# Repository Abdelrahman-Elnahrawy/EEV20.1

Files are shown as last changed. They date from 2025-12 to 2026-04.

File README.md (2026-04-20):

# EEV20.1 – Emergency Electronic Ventilator

<p align="center">
  EEV20.1 3D Model
</p>

<p align="center">
  
  
  
  
</p>
</p>

---

## 📌 Overview

**EEV20.1** is an **Emergency Electronic Ventilator prototype** developed as an open-source engineering project.  
The goal of this project is to demonstrate a **complete ventilator system design**, including:

- Mechanical structure
- Pneumatic system
- Embedded firmware
- Control logic
- Documentation & 3D visualization

> ⚠️ **Disclaimer:**  
> This project is intended **for educational, research, and prototyping purposes only**.  
> It is **NOT a certified medical device** and must not be used for real patients without proper medical approvals.

---

## 🎥 3D Model Preview

The following GIF shows the **actual 3D model** included in this repository:

<p align="center">
  EEV20.1 3D Model
</p>

The original 3D assets are available in **GLB format** inside the `docs/` directory.

---
🖼️ Circuit Diagram
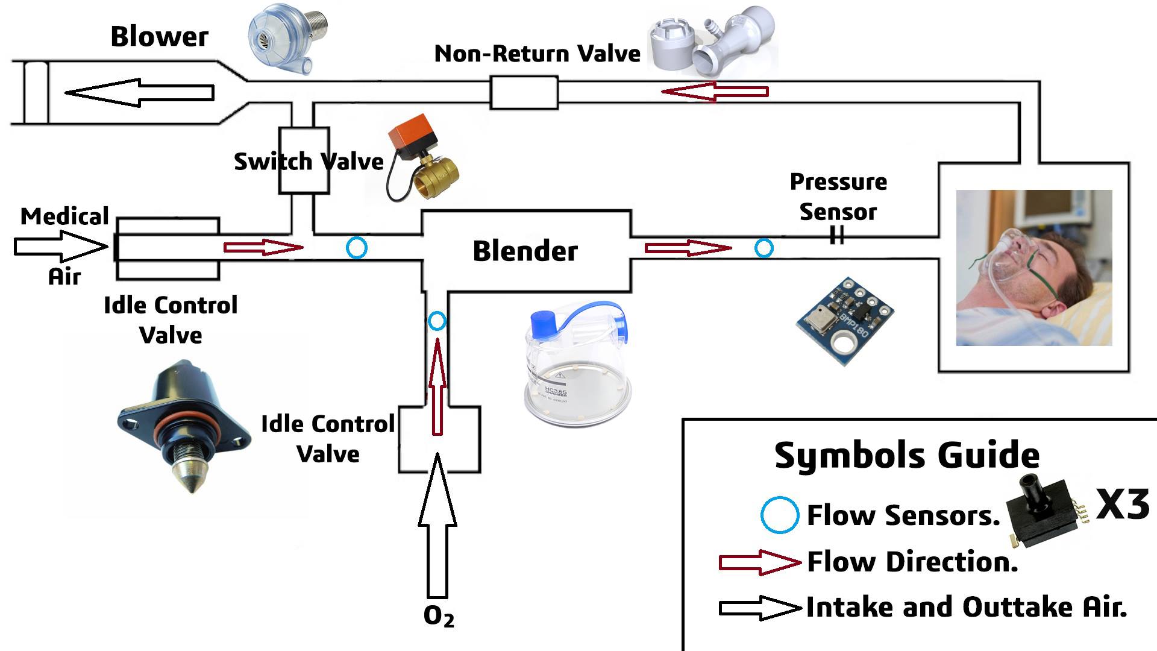
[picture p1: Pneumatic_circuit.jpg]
EEV20.1 Pneumatic Circuit
<p align="center">

*Figure 2: Pneumatic schematic showing flow paths and control valves.*

### 🔍 Operational Principle / فكرة العمل

* **Mixing Phase (مرحلة الخلط):** Controlled by stepper motors, the Air and $O_2$ valves open to a specific ratio to achieve the target $FiO_2$.
* **Delivery Phase (مرحلة الضخ):** The mixture is pressurized and delivered to the patient through a regulated flow path.
* **Exhalation (الزفير):** The system manages the exhalation valve to maintain **PEEP** (Positive End-Expiratory Pressure) if required.

---

## 📂 Repository Structure / هيكل المشروع

```text
EEV20.1/
├── .gitattributes                       # Git configuration for line endings, etc.
├── LICENSE                              # MIT License file
├── bill of materials.docx                # Complete parts list for the ventilator
├── EEV 20 ventilator User manual.pdf    # Main user manual PDF
├── Product_vision.gif                    # GIF preview of the 3D model
├── Pneumatic_circuit.jpg                 # Pneumatic system diagram
├── README.md                             # This file
├── docs/                                 # 3D models & viewer assets
│   ├── Body Design Containing Control Components.SLDPRT  # Solidworks CAD file of main enclosure & control
│   ├── index.html                        # Web page for 3D model viewing
│   ├── PCBs_Schematics.pdf               # PDF of PCB schematics
│   ├── Product_vision.glb                # 3D model of final product (GLB format)
│   ├── Product_vision.mp4                # Video render of the product
│   ├── Prototype.glb                     # 3D model of prototype version
│   └── Prototype.mp4                     # Video render of prototype
├── Render Prev images/                    # Screenshots & renders of components
│   ├── 2 Idle Valves.PNG
│   ├── Blower.PNG
│   ├── Design.PNG
│   ├── Humidifier.PNG
│   ├── keypad.PNG
│   ├── LCD.PNG
│   └── non return valve.PNG
└── Ventilation_Firmware_ATmega128A/      # Embedded firmware for ATmega128A
    ├── README.md                         # Firmware-specific README with build instructions
    ├── main.c                            # Main program entry point
    ├── app/                              # Application-level logic
    │   ├── ventilation_fsm.c             # Finite State Machine implementation
    │   └── ventilation_fsm.h             # FSM header
    ├── config/                           # Configuration files
    │   └── ventilation_config.h          # Configurable parameters for firmware
    ├── control/                          # Control modules
    │   ├── ventilation_idle_stepper_control.c  # Idle stepper motor control logic
    │   └── ventilation_idle_stepper_control.h  # Header for stepper control
    ├── drivers/                          # Low-level hardware drivers
    │   ├── lcd_driver.c                  # LCD screen driver
    │   ├── lcd_driver.h                  # LCD driver header
    │   ├── stepper_driver.c              # Stepper motor driver
    │   └── stepper_driver.h              # Stepper driver header
    ├── logic/                             # Computational logic modules
    │   ├── ventilation_machine_calculations.c   # Core ventilation calculations
    │   └── ventilation_machine_calculations.h   # Header for calculations
    ├── safety/                            # Safety and alarms
    │   ├── ventilation_safety.c          # Safety functions (limits, alarms)
    │   └── ventilation_safety.h          # Header for safety functions
    ├── ui/                                # User interface modules
    │   ├── ventilation_lcd.c             # LCD interface code
    │   └── ventilation_lcd.h             # LCD interface header
    └── v3_old/                            # Previous versions / prototypes
        ├── Air_flow_sensors_V1/          # Air flow sensor firmware
        │   ├── Air_Flow_Sensors_V1.cpp
        │   ├── Air_Flow_Sensors_V1.h
        │   └── Air_flow_sensors_V1.ino
        ├── mqtt_ventilation_machine_V1/  # MQTT-enabled prototype
        │   ├── ESP8266_MQTT_Client_V1.cpp
        │   ├── ESP8266_MQTT_Client_V1.h
        │   └── ESP8266_MQTT_Client_V1.ino
        ├── ventilation_control_pad_V2/   # Control pad prototype V2
        │   ├── ventilation_control_pad_V2.cpp
        │   ├── ventilation_control_pad_V2.h
        │   └── ventilation_control_pad_V2.ino
        ├── ventilation_idle_stepper_control/  # Old idle stepper control
        │   ├── ventilation_idle_stepper_control.cpp
        │   ├── ventilation_idle_stepper_control.h
        │   └── ventilation_idle_stepper_control.ino
        ├── ventilation_lcd_V3/            # Old LCD V3 code
        │   ├── ventilation_lcd_V3.cpp
        │   ├── ventilation_lcd_V3.h
        │   └── ventilation_lcd_V3.ino
        └── ventilation_machine_calculations/  # Old calculation modules
            ├── ventilation_machine_calculations.cpp
            ├── ventilation_machine_calculations.h
            └── ventilation_machine_calculations.ino
                          # Main project readme
```

## 🛠 System Components

### 🔌 Embedded System
- **Microcontroller:** ATmega128A
- **Language:** C (Bare-metal / AVR)
- **Architecture:** Modular & layered
- **Purpose:** Motor control, timing, safety logic, system states

### 🫁 Pneumatic System
- Pressure control
- Air flow regulation
- Safety relief mechanisms  
(see `Pneumatic_circuit.jpg`)

### 🧱 Mechanical Design
- Custom enclosure
- Motor-driven compression mechanism
- Designed for manufacturability & prototyping

---

## 📘 Documentation

Available documents include:

- **User Manual**
- **Pneumatic Circuit Diagram**
- **PCB & Electrical Schematics**
- **Project Reports & Presentations**

All documents are available directly in the repository as PDFs or inside the `Documentation/` folder.

---

yaml
Copy code

It includes:
- Low-level drivers
- Control logic
- Timing & safety handling
- Modular structure suitable for extension

📄 Please refer to the **README inside the firmware folder** for:
- Build instructions
- Code architecture
- Configuration details

---

## ⚠️ Safety Notice

- ❌ Not FDA / CE approved  
- ❌ Not clinically tested  
- ❌ Not intended for real medical use  

This project is shared **for learning and engineering demonstration only**.

---

## 📜 License

This project is licensed under the **MIT License**.

MIT License

Copyright (c) 2025 Abdelrahman Elnahrawy

Permission is hereby granted, free of charge, to any person obtaining a copy
of this software and associated documentation files...

yaml
Copy code

---

## 👤 Author

**Abdelrahman Elnahrawy**  
Embedded Systems & Mechatronics Engineer  

🔗 GitHub:  
https://github.com/Abdelrahman-Elnahrawy

---

## ⭐ Acknowledgment

If this project helped you learn or inspired your work, consider starring the repository ⭐  
and sharing it with the engineering community.

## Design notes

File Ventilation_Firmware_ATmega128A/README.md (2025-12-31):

# 🫁 Ventilation Machine Firmware (ATmega128A)








A modular, non-blocking firmware architecture for a microcontroller-based mechanical ventilation system, designed for **ATmega128A**.

This project focuses on **clean separation of concerns**, **safety**, and **real-time behavior**, making it suitable for research, academic, and prototype medical devices.

---

## 📌 Features

- ✅ Non-blocking architecture (millis / timers)
- ✅ Finite State Machine (FSM) control
- ✅ Safety & alarm layer (leakage detection)
- ✅ Stepper-based air & oxygen valve control
- ✅ LCD-based user interface (16x4)
- ✅ Expandable and RTOS-ready structure
- ✅ Medical-oriented design separation

---

## 🧠 System Architecture

The firmware is divided into clear functional layers:

UI (LCD)
│
FSM (Application Logic)
│
Control (Stepper / Valves)
│
Logic (Breathing Timing & Calculations)
│
Safety (Flow Validation & Alarms)
│
Drivers (LCD / Stepper)

yaml
Copy code

Each layer is **independent**, testable, and reusable.

---

## 📁 Folder Structure

Ventilation_Firmware_ATmega128A/
│
├── main.c
│
├── app/
│ ├── ventilation_fsm.h
│ ├── ventilation_fsm.c
│
├── control/
│ ├── ventilation_idle_stepper_control.h
│ ├── ventilation_idle_stepper_control.c
│
├── logic/
│ ├── ventilation_machine_calculations.h
│ ├── ventilation_machine_calculations.c
│
├── ui/
│ ├── ventilation_lcd.h
│ ├── ventilation_lcd.c
│
├── safety/
│ ├── ventilation_safety.h
│ ├── ventilation_safety.c
│
├── drivers/
│ ├── stepper_driver.h
│ ├── stepper_driver.c
│ ├── lcd_driver.h
│ ├── lcd_driver.c
│
├── config/
│ └── ventilation_config.h
│
└── README.md

yaml
Copy code

---

## ⚙️ Hardware Requirements

- **Microcontroller:** ATmega128A  
- **Display:** 16x4 LCD (HD44780 compatible)  
- **Actuators:** Stepper motors (Air & Oxygen idle valves)  
- **Sensors:**  
  - Air flow sensor  
  - Oxygen flow sensor  
- **Drivers:** ULN2003 / A4988 (or similar)

---

## 🔄 Finite State Machine (FSM)

The ventilation cycle is controlled using an FSM:

| State | Description |
|---|---|
| INIT | System initialization |
| STANDBY | Idle state |
| INHALE | Active air & oxygen delivery |
| EXHALE | Passive exhalation |
| ALARM | Safety fault detected |

State transitions are **time-based and safety-driven**.

---

## 🛡️ Safety Mechanism

The safety layer continuously verifies:

Patient Flow ≈ Air Flow + Oxygen Flow

yaml
Copy code

If deviation exceeds ±5%:
- Alarm state is triggered
- Valve motion stops
- LCD shows leakage warning

---

## 🧮 Breathing Calculations

- Inhale / Exhale timing derived from:
  - Respiratory rate
  - I:E ratio
- All timing is **non-blocking**
- Ready for pressure-based termination upgrade

---

## 📺 User Interface (LCD)

The LCD displays:

- Maximum Pressure
- Oxygen %
- Respiratory Rate
- Tidal Volume
- I/E Ratio
- Ventilation Mode
- Alarm Messages

---

## 🔧 Stepper Control Logic

Stepper motors regulate:
- Air valve opening
- Oxygen valve opening

Control is based on:
- Required flow (calculated)
- Measured flow (sensor feedback)

> Structure is PID-ready (future upgrade).

---

## 🚀 How to Build

- Toolchain: **AVR-GCC**
- IDEs:
  - MPLAB X
  - Atmel Studio
  - PlatformIO

Compile and flash to ATmega128A using your preferred programmer.

---

## ⚠️ Disclaimer

> **This project is for educational and research purposes only.**  
>  
> The algorithms and calculations are **NOT medically certified** and **must not** be used in life-support systems without proper validation, certification, and regulatory approval.

---

## 👨‍💻 Author

**Abdelrahman Elnahrawy**  
Embedded Systems & R&D Engineer  

---

## 📜 License

MIT License

Permission is hereby granted, free of charge, to any person obtaining a copy  
of this software and associated documentation files (the "Software"), to deal  
in the Software without restriction.

---

## 🔮 Future Improvements

- PID-based flow control
- Pressure-triggered inhale termination
- EEPROM patient profiles
- FreeRTOS port
- MQTT / Telemetry support
- SD card data logging

---

⭐ If you find this project useful, feel free to star the repository.

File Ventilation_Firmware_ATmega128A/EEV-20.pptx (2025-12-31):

## EEV-20.1

ETNAFS Team

## Medical ventilators and COVID-19

- 30% of Covid-19 hospitalized patients are likely to require mechanical ventilation (estimated 450,000 ventilator world wide in ninth of April 2020)
- The mechanical ventilators prices can range from $5,000 to $50,000.

## EEV-20.1

- EEV-20.1 have 3 ways of power
1. Internal rechargeable battery sustain the device for more than 1 hour.
2. 12Volt 3 ampere power supply.
3. Two 9 volt batteries.

## EEV-20.1

- Adjustable modes
            1. Continuous Positive Airway Pressure. (CPAP)
            2. Continuous Mandatory Ventilation. (CMV)
            3. Synchronous Intermittent Mandatory Ventilation. (SIMV)
            4. Airway Pressure Release Ventilation. (APRV)
            5. Pressure Support Ventilation. (PSV)
- Range 5 to 37 cm H O adjustable in 1 cmH O increment(+-0.001cmH O).
- Expiratory ratio (I:E) adjustable in the range 1.0 to 4.0 in 1 increment.
- Range 10 to 30 breaths per minute in increments of 1 (+-1breath).
- Tidal Volume (Vt) optionally Range 250 to 800 ml in steps of 10ml (+-30ml).
- Oxygen percent control range 21% to 100% increments of 1% (+-2 %).

2

2

2

## EEV-20.1 works in two different enviroments

1. Hospital (medical air system)


## EEV-20.1 works in two different enviroments

2. Field hospital

## Monitoring and Control EEV-20.1

Step 1
Install ETNAFS App.
Step 2
Scan Device QR-code
Step 3
Monitor the graphs

- Monitor from any device by MQTT
- Easy to control

## EEV-20.1 Mechanical Properties

1- Simplicity.
2- Low Weight ( Doesn’t Exceed 3kg )
3- Will be injected in a Plastic Mold (Material - - -> Plastic ABS)
4- Each Mechanical & Pneumatic Component are widely available in Egypt

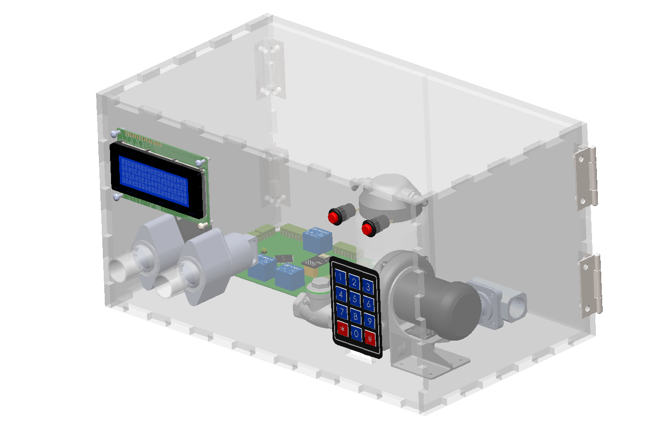
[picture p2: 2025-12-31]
Render Prev images/Design.PNG

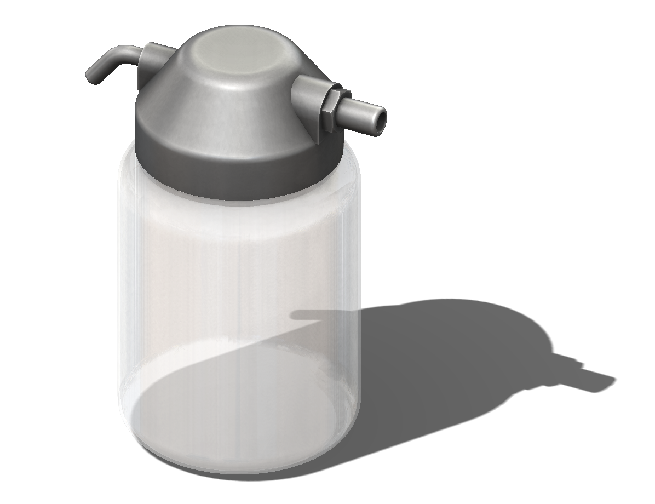
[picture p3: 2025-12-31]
Render Prev images/Humidifier.PNG

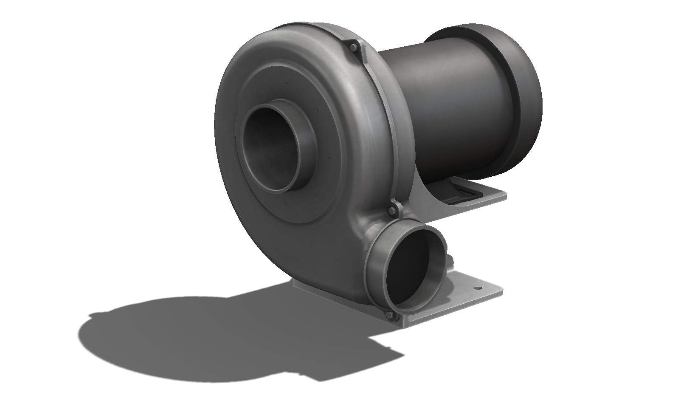
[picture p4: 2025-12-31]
Render Prev images/Blower.PNG

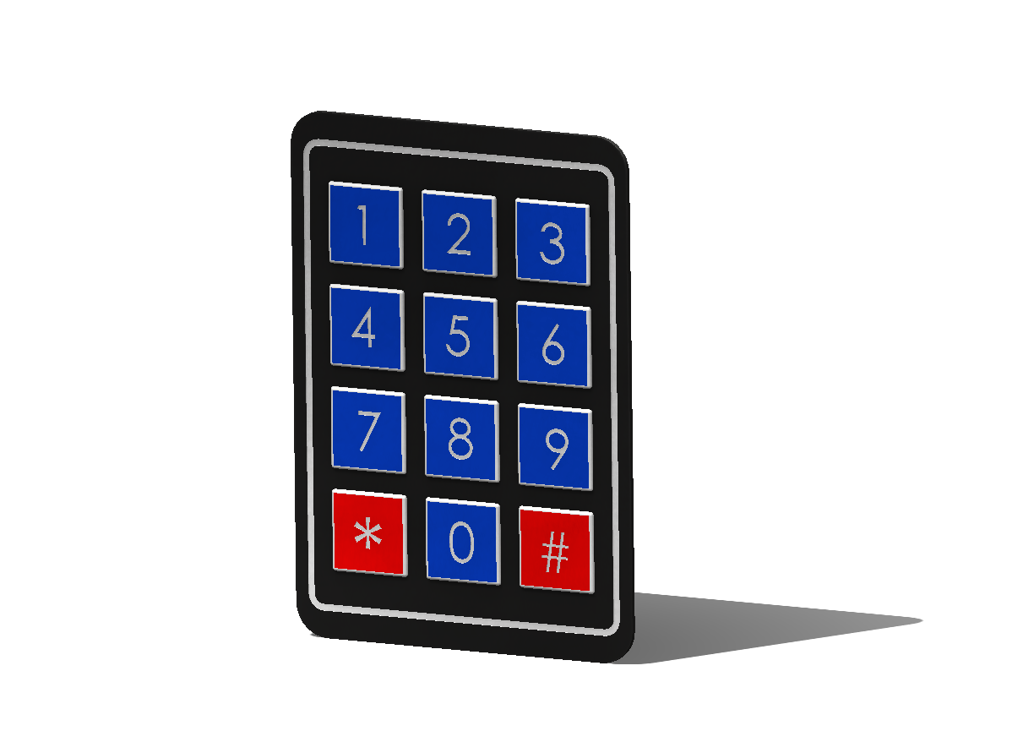
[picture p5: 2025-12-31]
Render Prev images/keypad.PNG

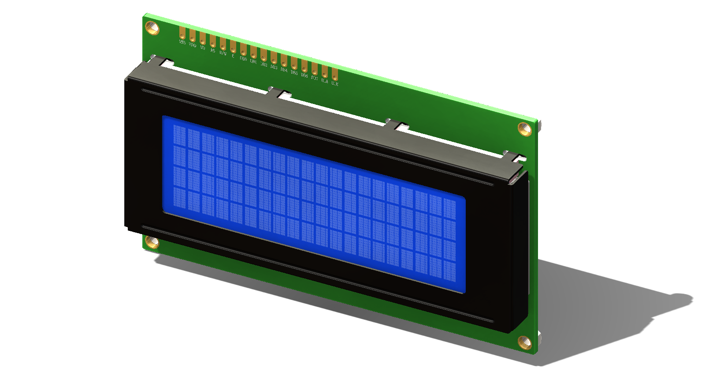
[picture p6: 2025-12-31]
Render Prev images/LCD.PNG

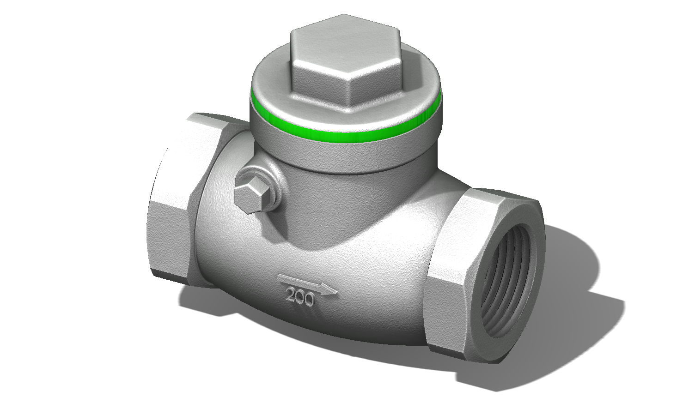
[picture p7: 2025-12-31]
Render Prev images/non return valve.PNG

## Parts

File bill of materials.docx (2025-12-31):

Part name | description | No. | Price each | Price
IAC valve 4-pins | Any 4 pins valve will work | 2 | 10 USD | 20 USD
Non-return Valve | | 1 | 1USD | 1USD
Solenoid Switch Valve | | 1 | 4USD | 4USD
DC motor | 12V DC 6000 RPM | 1 | 15 USD | 15USD
Atmega 128A/AU | Datasheet (http://ww1.microchip.com/downloads/en/devicedoc/atmel-8151-8-bit-avr-atmega128a_datasheet.pdf) | 1 | 4 USD | 4USD
ESP-01 | Wi-Fi module | 1 | 4USD | 4USD
L298N | Datasheet (https://www.sparkfun.com/datasheets/Robotics/L298_H_Bridge.pdf) | 2 | 2USD | 4USD
BMP 180 (Bosch) | Datasheet (https://cdn-shop.adafruit.com/datasheets/BST-BMP180-DS000-09.pdf) | 1 | 4 USD | 4USD
MXPM5053 GS | Datasheet (https://www.nxp.com/docs/en/data-sheet/MPX2053.pdf) | 3 | 2 USD | 6USD
AD623 | Analog convertor for MXPM5053 GS | 3 | 2USD | 6USD
LCD 1604A | | 1 | 5USD | 5USD
Relay 5V+BC547 transistor+ 2N2007diode | More than 2A/12V | 1 | 0.5 USD | 0.5USD
Resistors/Tubes/Wires | | | | 2USD
Phoenix Contact MSTBA Series | 2*8 - Pin 12*2-Pin | | | 5USD
PCB | | | | 5USD
Ultracell Battery (UL5-12) | Ultracell Battery (UL5-12) Sealed Lead Acid Battery (12V/5A) | 1 | 15USD | 15USD
Estimated body cost in industrial production (1000-5000)( ABS plastic) | | | | 15USD
Total cost | | | | 115.5USD

ALL THE COMPONENTS PRICES DECREASE SIGNIFICANTLY IN INDUSTRIAL PRODUCTION

ESTIMETIED COST OF EACH DEVICE IN INDUSTRIAL PRODUCTION 70USD

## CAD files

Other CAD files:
docs/Body Design Containing Control Components.SLDPRT

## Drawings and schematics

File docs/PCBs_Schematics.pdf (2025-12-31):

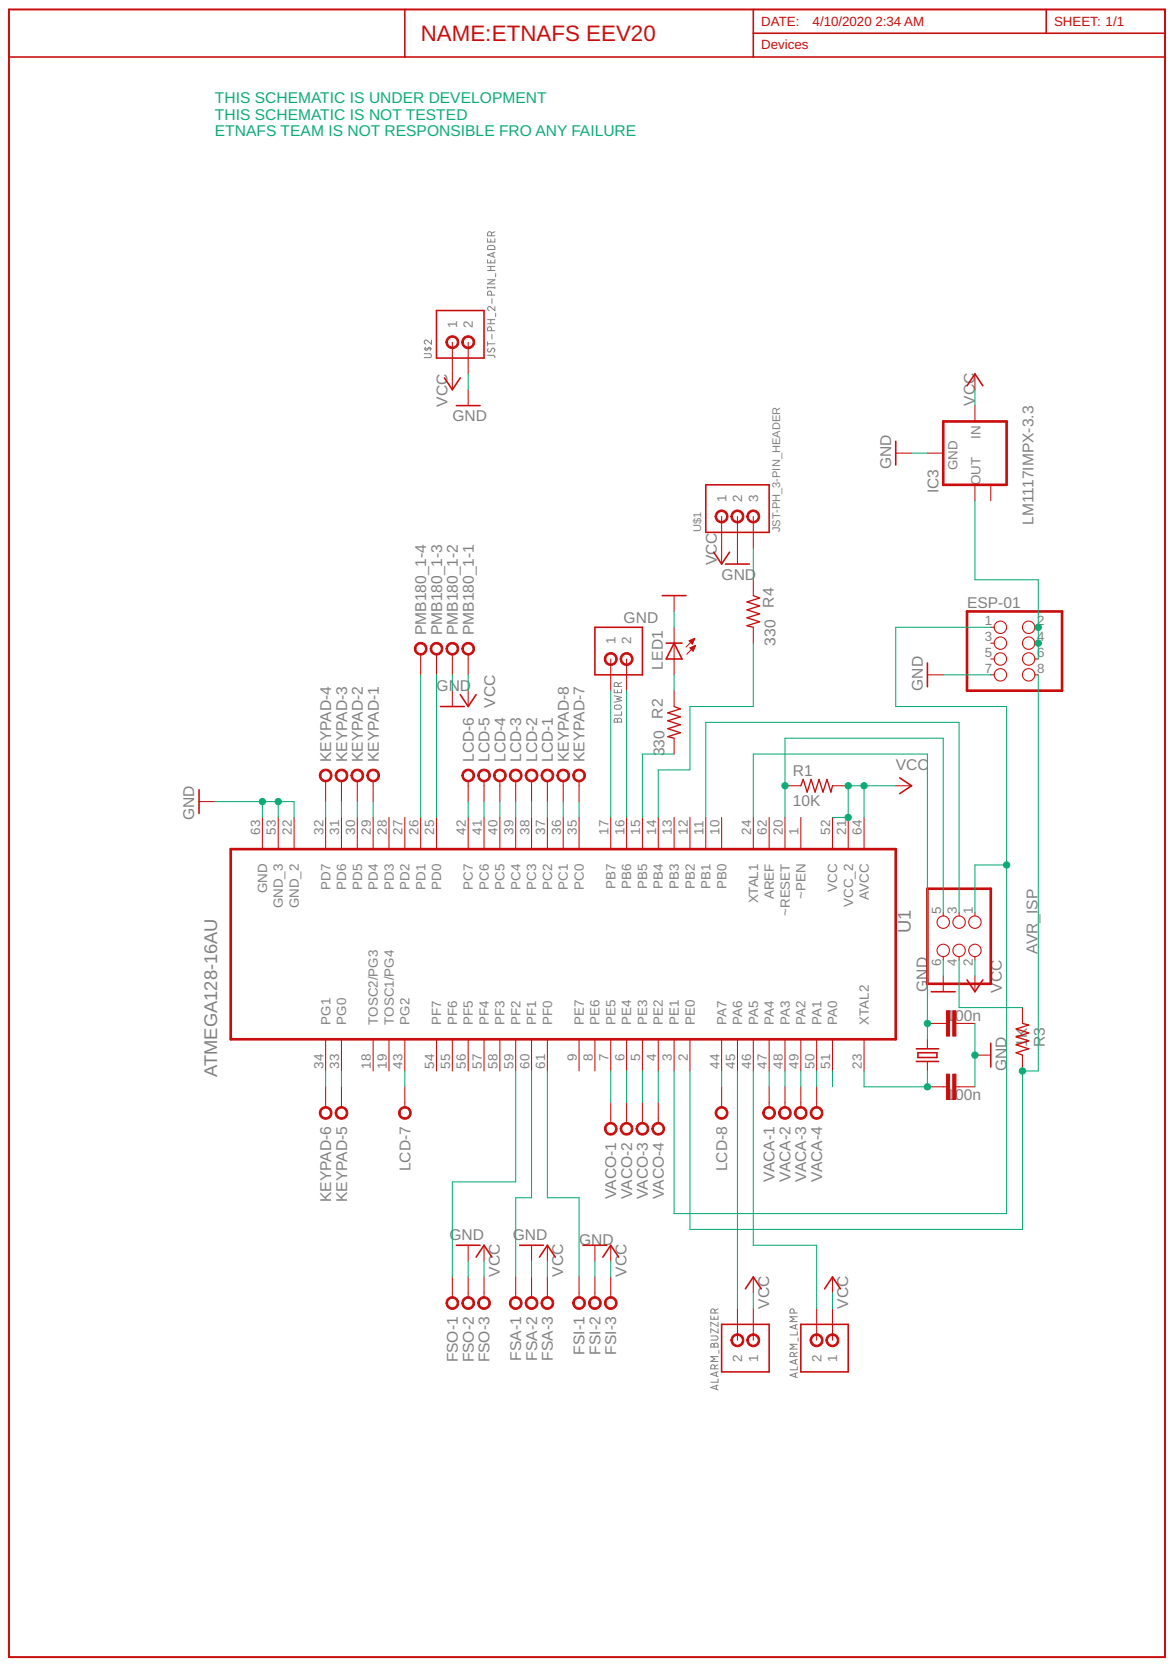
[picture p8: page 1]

2 NAME: DATE: Devices SHEET: ETNAFS EEV20

THIS SCHEMATIC IS NOT TESTED
ETNAFS TEAM IS NOT RESPONSIBLE FRO ANY FAILURE

KEYPAD-1 KEYPAD-2 KEYPAD-3 KEYPAD-4 KEYPAD-5 KEYPAD-6

VACO-1 VACO-2 VACO-3 VACO-4 VACA-1 VACA-2 VACA-3 VACA-4

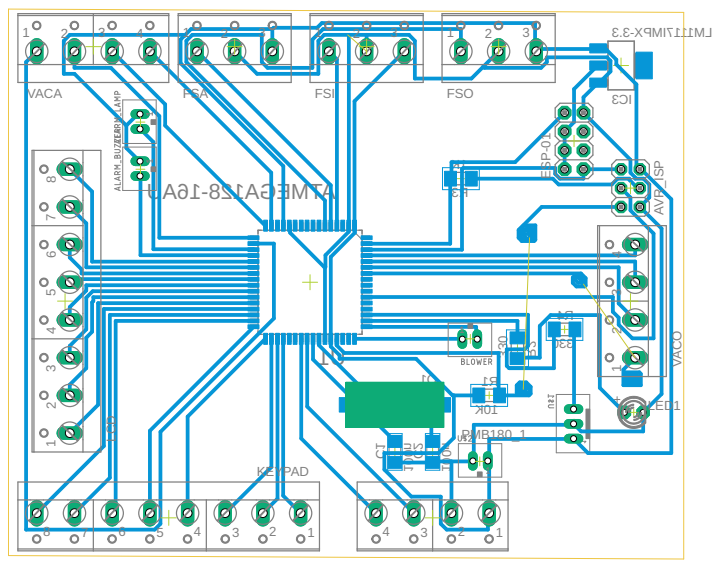
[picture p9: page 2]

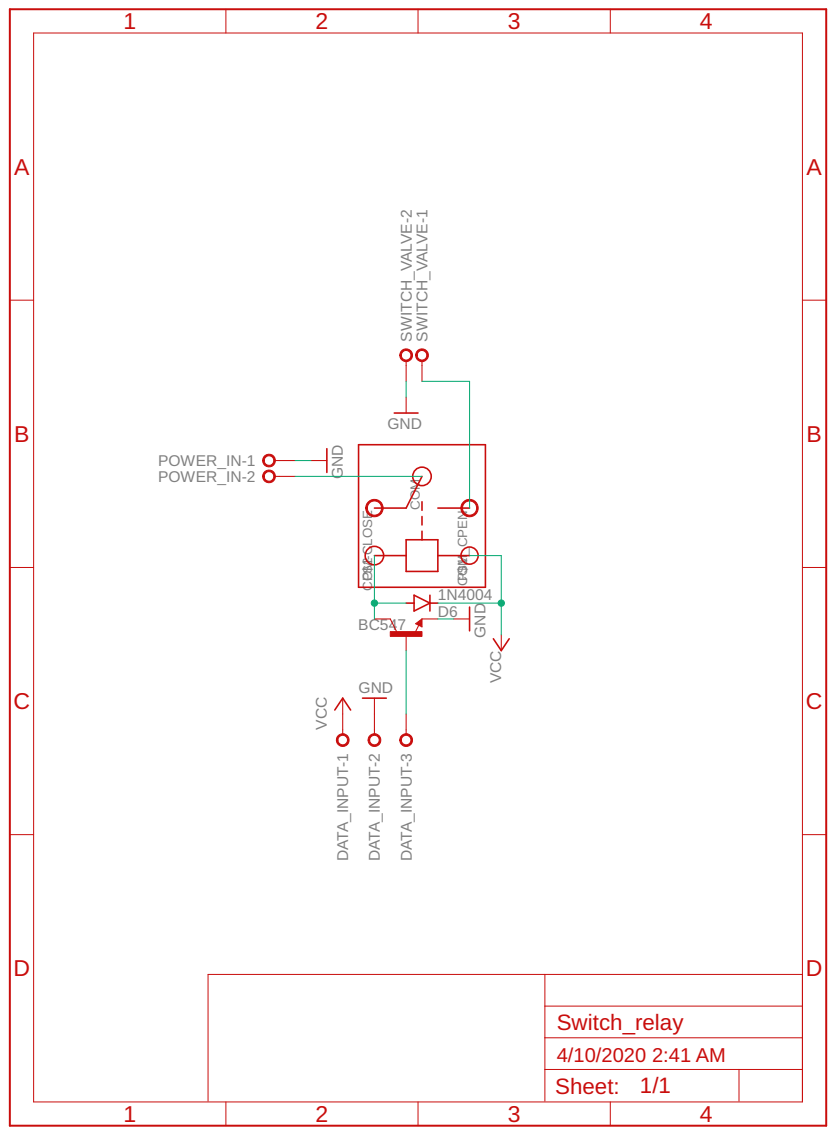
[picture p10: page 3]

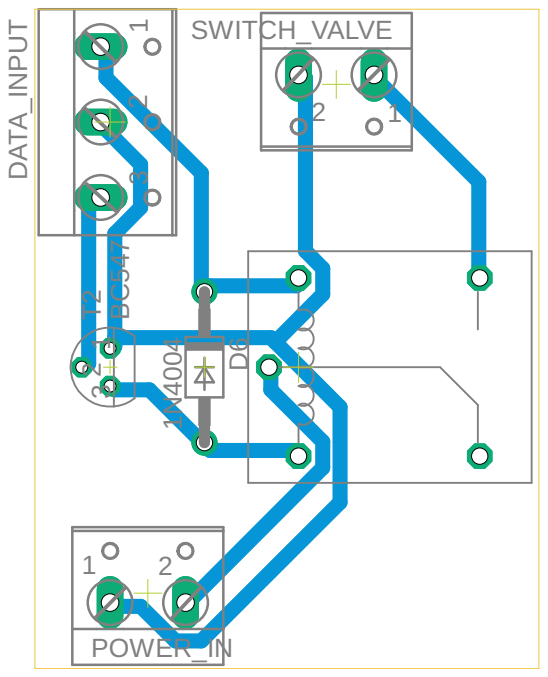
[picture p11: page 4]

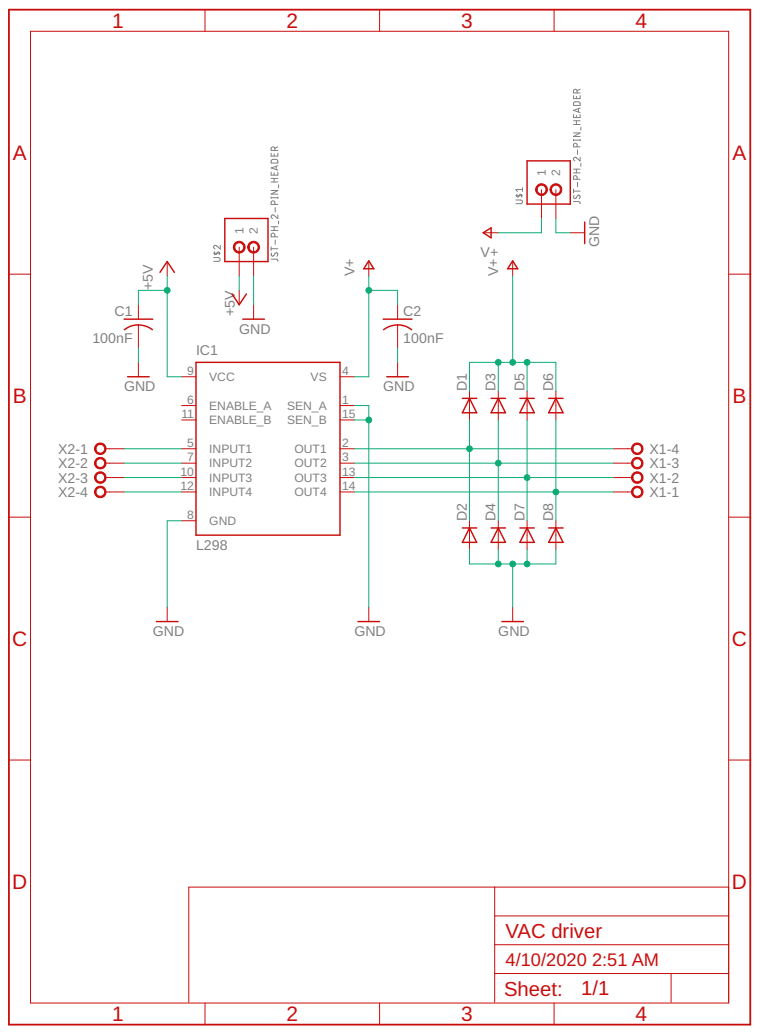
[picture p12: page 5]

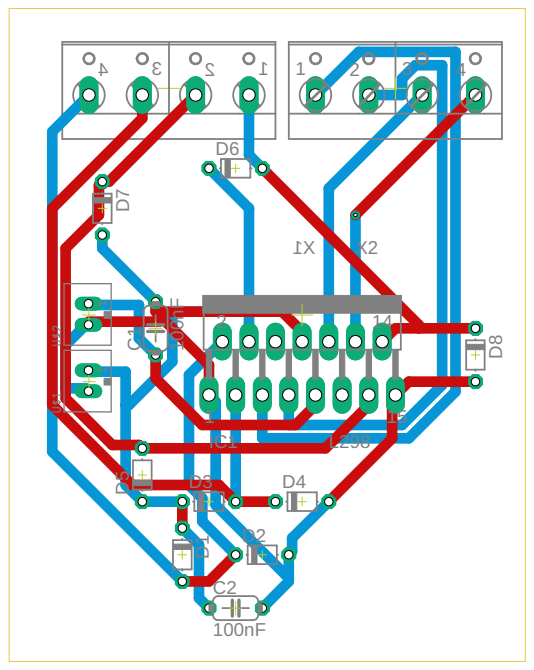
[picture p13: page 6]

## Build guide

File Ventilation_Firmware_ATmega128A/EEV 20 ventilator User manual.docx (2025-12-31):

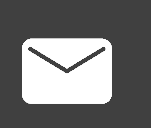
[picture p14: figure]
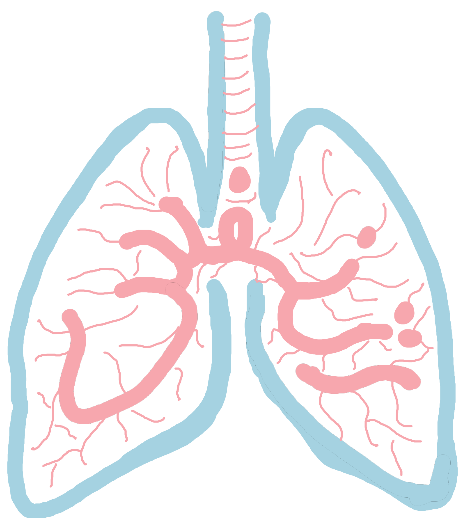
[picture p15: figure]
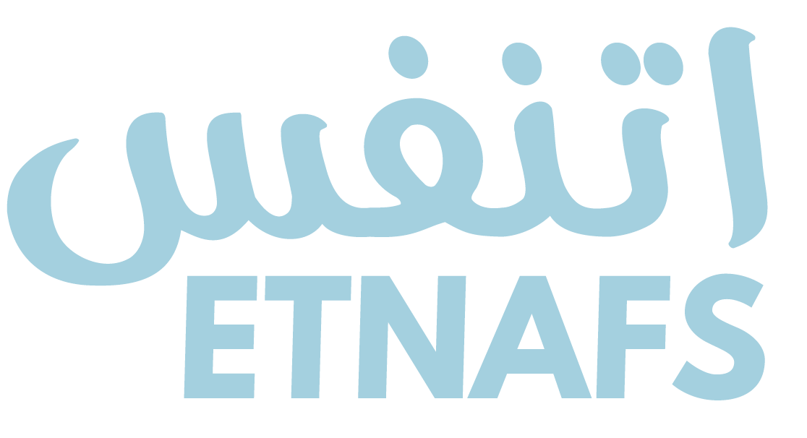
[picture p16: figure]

+2-011-23849195

EEV 20.1

ETNAFS@GMail.com

USER MANUAL

ETNAFS EMERGENCY VENTILATOR

## EEV 20 ventilator

### Parameters

- range 5 to 37 cm H2O adjustable in 1 cmH2O increment(+-0.001cmH2O)
- Monitor wirelessly over Wi-Fi network
- Air/Oxygen supply shouldn’t exceed 20 PSI
- Expiratory ratio (I:E) adjustable in the range 1.0 to 4.0 in 1 increment
- range 10 to 30 breaths per minute in increments of 1 (+-1breath)
- Tidal Volume (Vt) optionally Range 250 to 800 ml in steps of 10ml (+-30ml)
- 1 Hour rechargeable battery backup if power failure
- Oxygen percent control range 21% to 100% increments of 1% (+-2 %)
- The ability to input body weight and have volume calculated as, for example, 6ml/kg of ideal body weight

## Alarms

- gas or electricity supply failure
- machine switched off while in mandatory ventilation mode
- inspiratory airway pressure exceeded
- inspiratory pressure not achieved (equivalent to disconnection alarm)
- tidal volume not achieved or exceeded

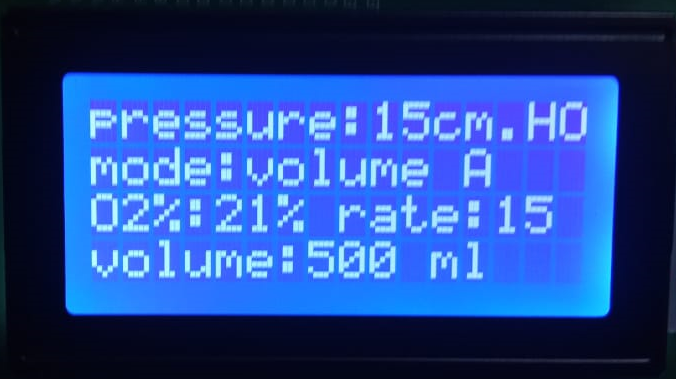
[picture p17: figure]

# Monitoring

### Modes

  I- Continuous Positive Airway Pressure (CPAP)
  II- Continuous Mandatory Ventilation (CMV)
  III- Synchronous Intermittent Mandatory Ventilation (SIMV)
  IV- Airway Pressure Release Ventilation (APRV)
  V- Pressure Support Ventilation (PSV)

# Wireless monitoring

1. Download ETNAFS android app from app store
2. Scan the device QR code
3. Monitor the device from your phone

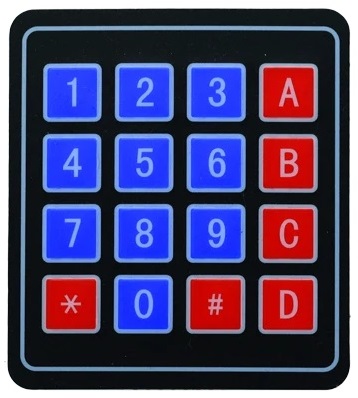
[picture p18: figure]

# Device control

# 1. Choose the parameter you want to change

# 2. Write the input

# 3. To change the mode just press on the mode button

# 4. To change the I:E ratio press on the I:E button

ETNAFS EMERGENCY VENTILATOR 20.1 – USER MANUAL

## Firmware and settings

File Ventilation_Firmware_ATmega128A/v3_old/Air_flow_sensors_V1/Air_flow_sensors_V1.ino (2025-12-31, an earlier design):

int ERORR;
float CurrentReadingO;
float SumO;
float AverageO;
float MeasuresNO=10 ; // number of measures to average
float OF;
float CurrentReadingA;
float SumA;
float AverageA;
float MeasuresNA=10 ;
float AF;
float CurrentReadingP;
float SumP;
float AverageP;
float MeasuresNP=10 ;
float PF;
// Patient air flow
float OFSUM;
// Oxygen flow summation over 3 sec
float AFSUM;
// Air flow summation over 3 sec
float PFSUM;
// Patient flow summation over 3 sec
unsigned long previousMillis1 = 0;
void setup() 
{
Serial.begin(9600);
}

void loop() 
{unsigned long currentMillis1 = millis();
for (int i=0; i<MeasuresNO; i++)
{
CurrentReadingO = analogRead(A5);
SumO+=CurrentReadingO;
delay(1);
}
for (int i=0; i<MeasuresNA; i++)
{
CurrentReadingA = analogRead(A6);
SumA+=CurrentReadingA;
delay(1);
}
for (int i=0; i<MeasuresNA; i++)
{
CurrentReadingA = analogRead(A6);
SumA+=CurrentReadingA;
delay(1);
}
for (int i=0; i<MeasuresNP; i++)
{
CurrentReadingP = analogRead(A6);
SumP+=CurrentReadingP;
delay(1);
AverageO=SumO/MeasuresNO;
SumO=0;
AverageA=SumA/MeasuresNA;
SumA=0;
AverageP=SumP/MeasuresNP;
SumP=0;
}

AverageO=SumO/MeasuresNO;
SumO=0;
AverageA=SumA/MeasuresNA;
SumA=0;
AverageP=SumP/MeasuresNP;
SumP=0;
OFSUM=OFSUM+AverageO;
AFSUM=AFSUM+AverageA; 
PFSUM=PFSUM+AverageP;
if (currentMillis1 - previousMillis1 >=3000) {
if (PFSUM < (AFSUM+OFSUM)*.95 || PFSUM > (AFSUM+OFSUM)*1.05){
  ERORR=1;}
OFSUM=0;
AFSUM=0; 
PFSUM=0;  
}

/* This equation is not tested
this equation is not valid
etnafis team is not responsible of any damage
I used this linear equation to test on fan I had access to*/
OF=(AverageO-68)*0.265+2.7;
AF=(AverageO-68)*0.265+2.7;   
PF=(AverageO-68)*0.265+2.7;
}
